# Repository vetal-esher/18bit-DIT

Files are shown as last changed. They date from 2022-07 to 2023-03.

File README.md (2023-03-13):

# 18bit-DIT
Adding  digital output for old synths

Surely everyone who used to know DOS era met in games the choice of musical accompaniment - General MIDI, Roland Sound Canvas, Yamaha XG. I will not talk about what wonderful devices these are, and how well they played MIDI. Until the end of the 90s, all these home desktop romplers, like most other professional devices, had only analog outputs, however, they were quite acceptable in quality. In early 2010, out of nostalgia, I bought several devices of that era on ebay - these are the Roland Sound Canvas 88 Pro, <a href="https://github.com/vetal-esher/MT32-DIT">Roland MT-32</a>, Yamaha MU128 and Yamaha AN200. The first three should be familiar to gamers of the early 90s, while the AN200 module is an analog modeling synthesizer based on the Yamaha PLG150-AN plug-in card. Later Yamaha MU1000/2000 tone generators were also sold on the site - their difference from the MU128 consisted in a slightly expanded version of the sample bank, as well as in the presence of an optical TOSLINK output.

Actually, the presence of optics in the MU2000 prompted me to start comparing circuits to see if it was possible to modify the MU128 circuit and get a digital output on my own. In the MU2000 service manual, the optical output circuitry is based on a proprietary Yamaha YM3437C chip, which is very difficult to get for an ordinary radio amateur. We need to look for a more general DIT. A Google search on this topic led me to a <a href="https://nfggames.com/forum2/index.php?topic=4063.0">mod for MU10</a>. The author of the mod relied on the <a href="http://www3.big.or.jp/~fujikko/sc88vl/kaizo.html">Japanese mod for the Roland SC-88VL</a>. The mod is based on the TC9231N chip from Toshiba, which implements a digital audio interface according to the SPDIF/TOSLINK standard. The chip can be ordered on ebay, it costs an average of $ 2.5 per piece (note: this was in 2010, now the chip is almost impossible to find); the rest of the parts are sold at any radio store. I assembled a Japanese version on a breadboard, and it turned out to be working - with a small caveat. The DAC of the Roland SC88 is 18-bit, while the TC9231N is 16-bit. The Japanese author made a binding for this, which allows either cutting off the top 2 bits in the stream - which could lead to clipping, or shifting the stream 2 bits lower (cutting off the bottom 2 bits), which led to a decrease in volume. In any case, 2 bits of information were lost - and that did not suit me.
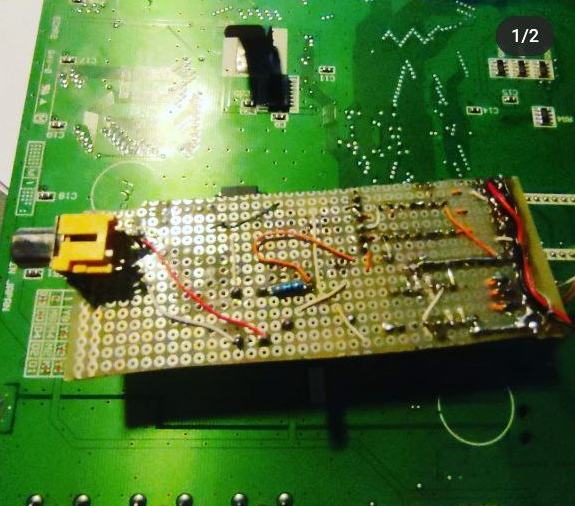
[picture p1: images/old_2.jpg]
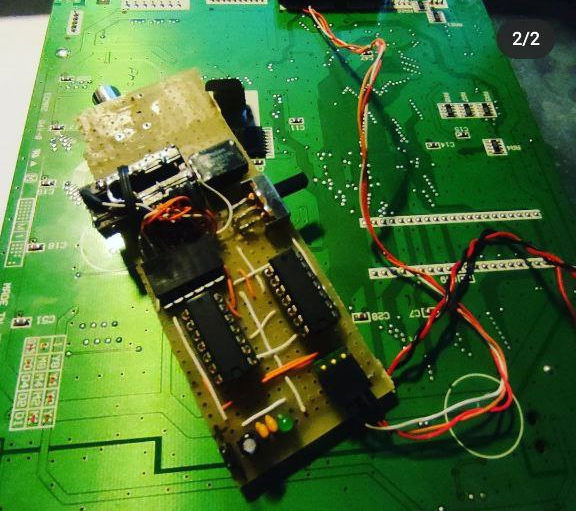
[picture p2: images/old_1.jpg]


I started looking for a transceiver that works with 18-bit stream in "hardware" mode, i.e. that does not require setting the operating mode using an additional microcontroller. After a lot of experimentation with DIT 4096, 4192, TC9271N and others, I finally found a transceiver that works native with 18-bit stream - AKM AK4103AVF. Thanks to the internal pull-up and pull-down resistors, you can build the scheme by minimum of components.

Let's sketch out the diagram first. Given that the board should be as versatile as possible, all configurable pins should be placed on jumpers. The output is bound according to the datasheet as consumer S/PDIF. If XLR AES3 (AES/EBU) is needed, see AK4103 datasheet, also there you need another configuration on FS0-FS3 pins.

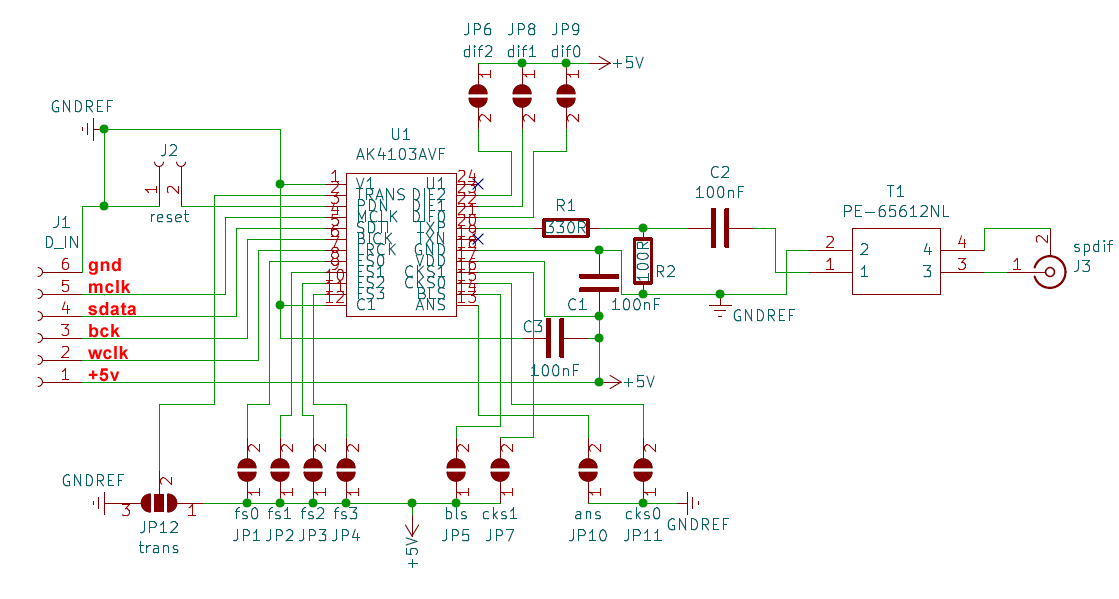
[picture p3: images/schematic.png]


The input is I2S, for this we need the sdata, lrck(wclk), bck and mclk lines on the sources. In different datasheets, these lines may be called differently, but their essence is always the same - DATA=SDATA=SI=MDAC=SDTI, LRCK=LRCX=MWCLK, CLK=MQCLK=BCK, etc. All of these lines should be easily found in the circuits included in the DAC, with the exception of mclk, which will have to be searched by the oscilloscope at different points in the circuit. Usually, in I2S, mclk is not needed for transmission, but in AK4103AVF the line is used for correct synchronization.

It has been noticed that if the circuit is turned on at the same time as the module, the AK4103 does not pick up the frequency and the digital output is silent. Empirically revealed that the frequency is caught after the initialization of the module, you need a power delay. In 2016, without thinking twice, I simply brought the "spdif reset" button to the case (shown in the diagram). At the beginning of June 2022, <a href="https://github.com/nikitalita/MU100-DIT">nikitalita</a> contacted me and suggested to use the BRESET line in the PLG expansion connector. An oscilloscope check revealed that BRESET remained low for about 70ms, which was enough for the DIT to pick up the frequency. Let's find the lines on all three devices:

<table border=1>
<tr><th>I2S</th><th>Roland SC-88 Pro</th><th>Yamaha MU128</th><th>Yamaha AN200</th></tr>
<tr><td>mclk</td>	<td>CN105 pin 5</td>	<td>IC39 pin 16</td>	<td>IC17 pin 160</td></tr>
<tr><td>sdata</td>	<td>CN105 pin 3</td>	<td>IC36 pin 15</td>	<td>IC16 pin 15</td></tr>
<tr><td>bck</td>	<td>IC35 pin 8</td>	<td>IC36 pin 16</td>	<td>IC16 pin 16</td></tr>
<tr><td>wclk</td>	<td>CN105 pin 6</td>	<td>IC36 pin 13</td>	<td>IC16 pin 13</td></tr>
<tr><td>reset</td>	<td>IC35 pin 9</td>		<td>IC34 pin 19</td>	<td>CN5 pin 4</td></tr>
</table>

<h3>Roland SC-88 Pro</h3>
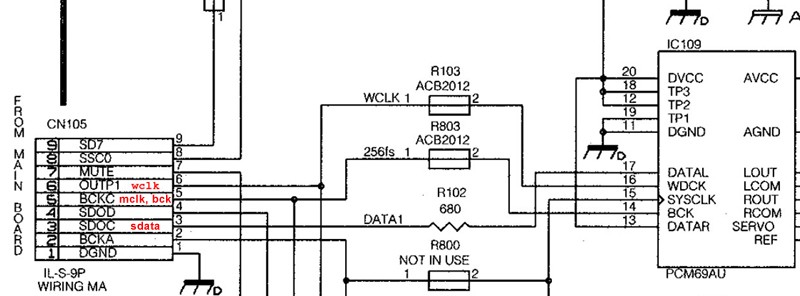
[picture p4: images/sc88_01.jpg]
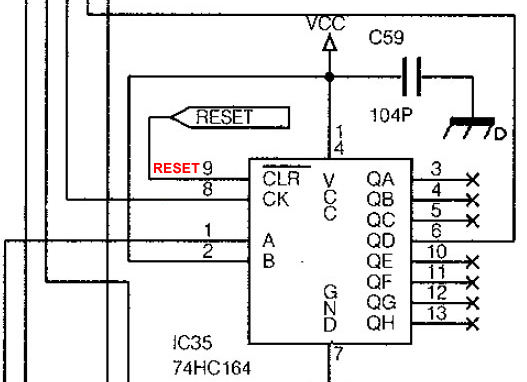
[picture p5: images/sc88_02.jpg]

<h3>Yamaha MU128</h3>
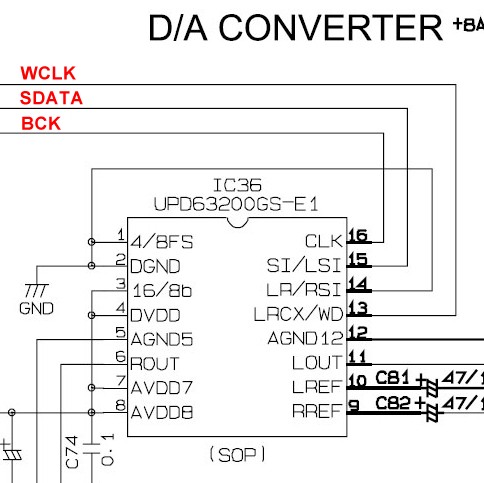
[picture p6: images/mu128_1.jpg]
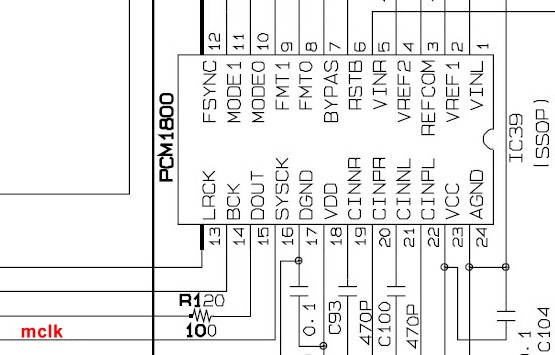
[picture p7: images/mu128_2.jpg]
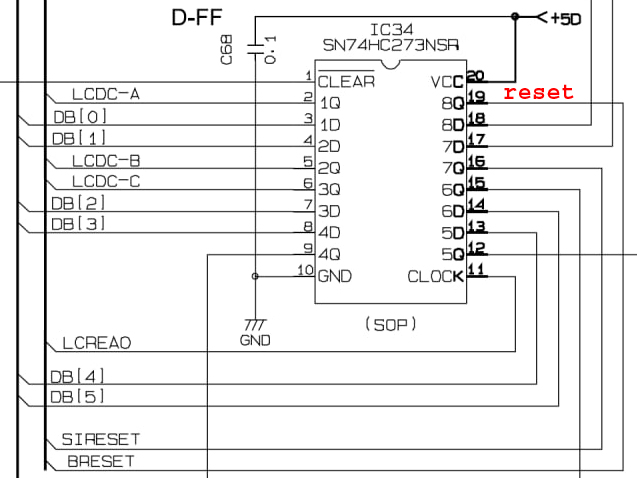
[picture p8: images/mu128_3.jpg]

<h3>Yamaha AN200</h3>
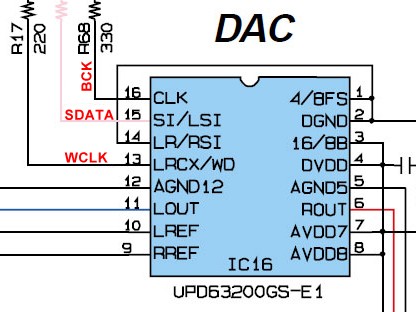
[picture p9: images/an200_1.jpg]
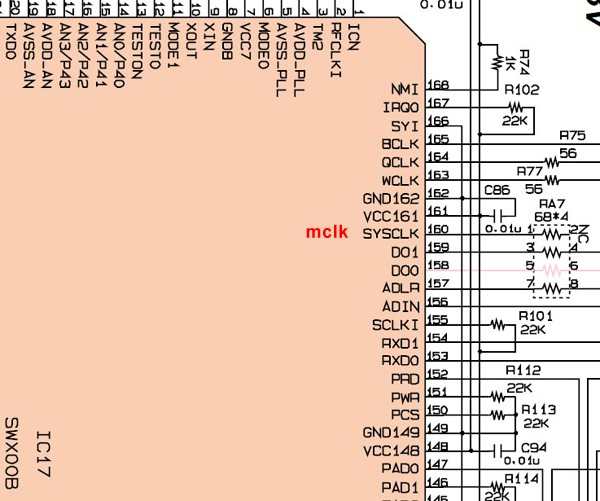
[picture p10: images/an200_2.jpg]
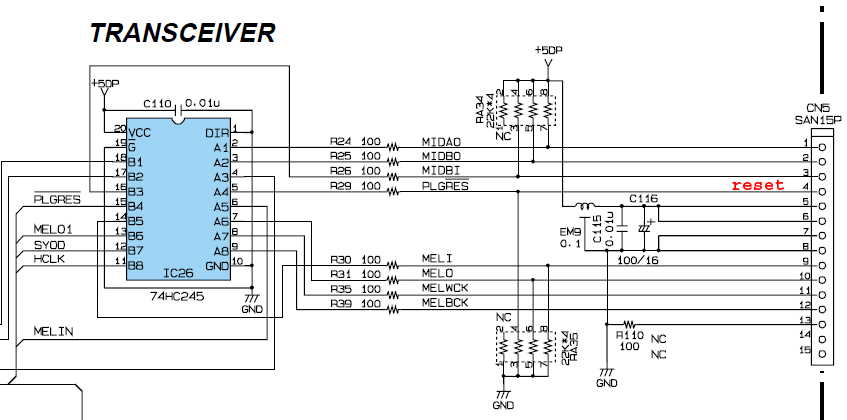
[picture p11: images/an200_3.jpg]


The SC88 has an 18-bit PCM69AU, while the MU128 and AN200 have an 18-bit NEC D63200. According to the specification, the SC-88 has a sample rate of 32kHz, MU128 and AN200 - 44kHz. Following the datasheet, we need to set the following modes: audio routing mode - normal, synchronous mode, 18bit right justified. Let's measure frequencies:
<table border=1>
<tr><th></th><th>wclk</th><th>mclk</th><th>bck</th><th>dif0</th><th>dif1</th><th>dif2</th><th>cks0</th><th>cks1</th><th>fs0</th><th>fs1</th><th>fs2</th><th>fs3</th></tr>

<tr><td>default</td><td>-</td><td>-</td><td>-</td><td>0</td><td>0</td><td>0</td><td>1</td><td>0</td><td>0</td><td>0</td><td>0</td><td>0</td></tr>
<tr><td>SC88</td>
<td>32000Hz</td><td>8.192 MHz</td><td>8.192 MHz</td>
<td>1</td><td>0</td><td>0</td>
<td>1</td><td>0</td>
<td>1</td><td>1</td><td>0</td><td>0</td>
</tr>
<tr><td>MU128</td>
<td>44100Hz</td><td>11.2896 MHz</td><td>2.8224 MHz</td>
<td>1</td><td>0</td><td>0</td>
<td>1</td><td>0</td>
<td>0</td><td>0</td><td>0</td><td>0</td>
</tr>
<tr><td>AN200</td>
<td>44100Hz</td><td>16.9344 MHz</td><td>2.8224 MHz</td>
<td>1</td><td>0</td><td>0</td>
<td>0</td><td>1</td>
<td>0</td><td>0</td><td>0</td><td>0</td>
</tr>
</table>

By the way, in 2010, the service manual for the MU128 could only be found on the same Ebay for money. I bought it, got a PDF, and immediately shared it on my site for free for everyone who seeks it. After a few weeks, this service manual was no longer sold :)

<p>This circuit was assembled on a breadboard and successfully worked in MU128 and AN200 in 2016.</p>

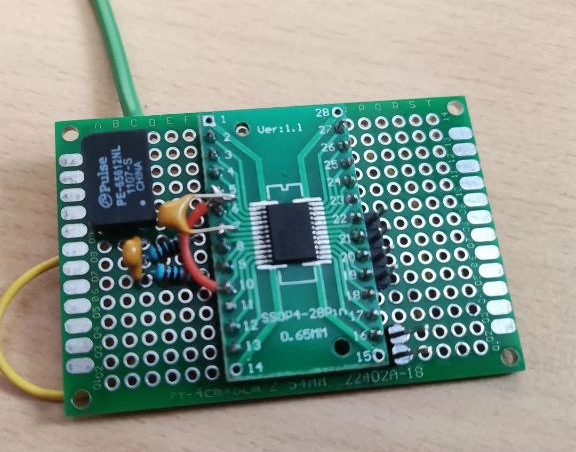
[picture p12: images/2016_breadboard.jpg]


In 2021, I suddenly decided to re-release the development in a decent way.

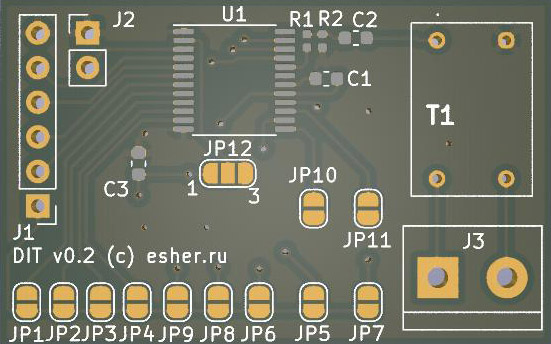
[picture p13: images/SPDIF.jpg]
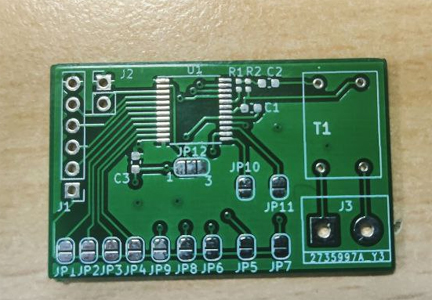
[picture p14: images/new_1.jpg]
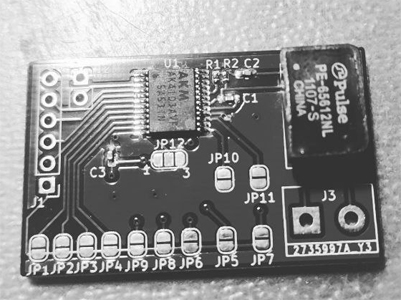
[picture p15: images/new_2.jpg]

<p>Gerbers: <a href="hardware/gerber/dit_0.2_gerber.zip">dit_0.2_gerber.zip</a></p>
<h2>Partlist</h2>
<table border=1>
<tr><th>Reference</th><th>Value</th><th>Package</th></tr>
<tr><td>U1</td><td>AK4103AVF</td><td>TSSOP-24</td></tr>
<tr><td>T1</td><td>PE-65612NL, TC-612</td><td></td></tr>
<tr><td>C1, C2, C3</td><td>100nF</td><td>0603</td></tr>
<tr><td>R1</td><td>330R</td><td>0402</td></tr>
<tr><td>R2</td><td>100R</td><td>0402</td></tr>
</table>

<h2>Roland SC88 Pro notes</h2>
<p>According to Japanese DIT project, the actual stream is 20bit, so AK4103 can be configured as 20-bit right justified, but you will get only significantly lower volume. This is the same melody recorded 20-bit first, then 18-bit:</p>

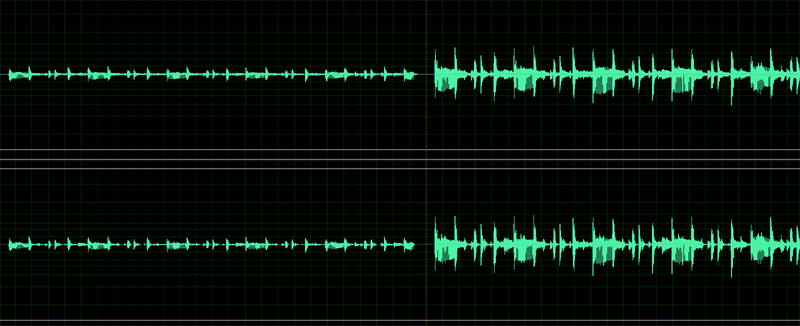
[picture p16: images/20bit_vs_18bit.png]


<h2>Links</h2>
<p><a href="https://esher.ru/blog/887.html">https://esher.ru/blog/887.html</a> My initial blog post in 2016 </p>
<p><a href="https://github.com/nikitalita/MU100-DIT">MU100-DIT</a>, a parallel project for MU-series using TOSLINK, by nikitalita</p>
<p><a href="https://kurohane.net/wiki/index.php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">Japanese project using AK4103 too</a></p>
<p><a href="https://esher.ru/i/f/887/887/AK4103AVF.pdf">AKM AK4103A datasheet</a></p>
<p><a href="https://esher.ru/i/f/900/900/an200sm.pdf.gz">Yamaha AN200 service manual</a></p>
<p><a href="https://esher.ru/i/f/888/888/Roland_SC-88Pro_ServiceNotes.pdf.gz">Roland SC88 Pro service notes (in japan)</a></p>
<p><a href="https://esher.ru/i/f/869/869/mu128sm-e.pdf.gz">Yamaha MU128 service manual</a></p>
<p><a href="https://github.com/vetal-esher/MT32-DIT">MT32-DIT, trying to SPDIF the legendary Roland MT-32</a></p>

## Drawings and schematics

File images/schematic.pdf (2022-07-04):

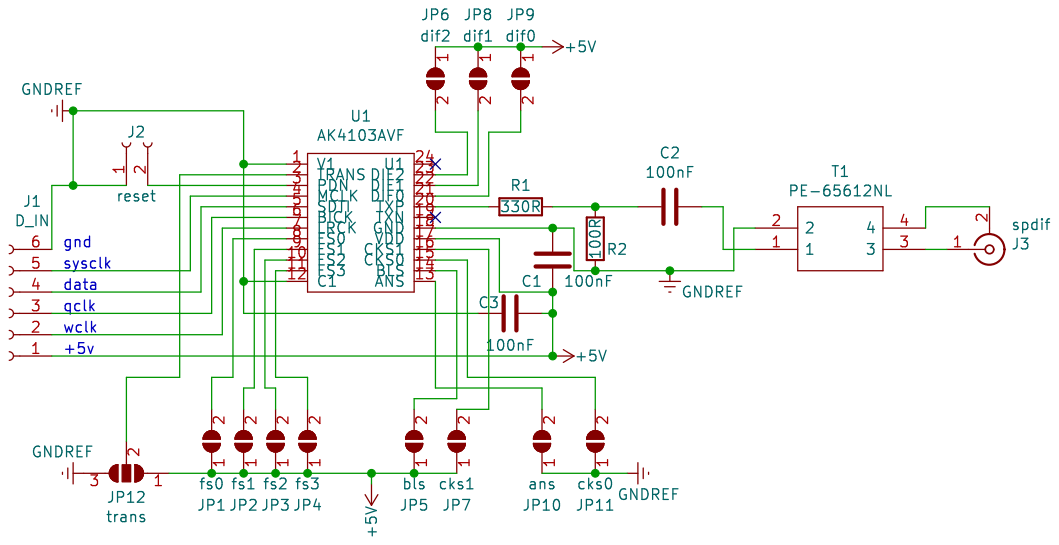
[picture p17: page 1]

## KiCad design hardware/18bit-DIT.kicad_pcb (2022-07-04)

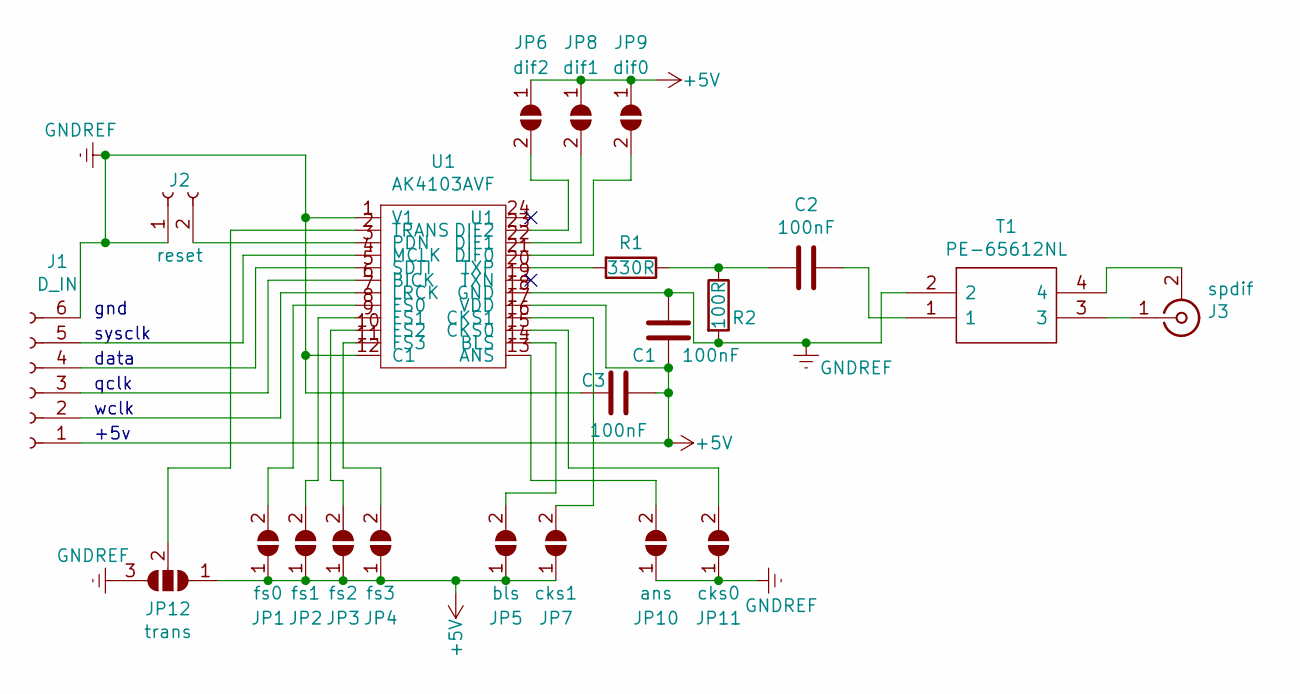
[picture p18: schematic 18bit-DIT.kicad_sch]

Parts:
C1, C2, C3: 100nF; C_0603_1608Metric
J1: D_IN; PinHeader_1x06_P2.54mm_Vertical
J2: reset; PinHeader_1x02_P2.54mm_Vertical
J3: spdif; TerminalBlock_bornier-2_P5.08mm
JP1: fs0; SolderJumper-2_P1.3mm_Open_RoundedPad1.0x1.5mm
JP2: fs1; SolderJumper-2_P1.3mm_Open_RoundedPad1.0x1.5mm
JP3: fs2; SolderJumper-2_P1.3mm_Open_RoundedPad1.0x1.5mm
JP4: fs3; SolderJumper-2_P1.3mm_Open_RoundedPad1.0x1.5mm
JP5: bls; SolderJumper-2_P1.3mm_Open_RoundedPad1.0x1.5mm
JP6: dif2; SolderJumper-2_P1.3mm_Open_RoundedPad1.0x1.5mm
JP7: cks1; SolderJumper-2_P1.3mm_Open_RoundedPad1.0x1.5mm
JP8: dif1; SolderJumper-2_P1.3mm_Open_RoundedPad1.0x1.5mm
JP9: dif0; SolderJumper-2_P1.3mm_Open_RoundedPad1.0x1.5mm
JP10: ans; SolderJumper-2_P1.3mm_Open_RoundedPad1.0x1.5mm
JP11: cks0; SolderJumper-2_P1.3mm_Open_RoundedPad1.0x1.5mm
JP12: trans; SolderJumper-3_P1.3mm_Open_RoundedPad1.0x1.5mm_NumberLabels
R1: 330R; R_0402_1005Metric
R2: 100R; R_0402_1005Metric
T1: PE-65612NL; PE65612NL; Manufacturer_Part_Number PE-65612NL; Mouser Part Number 673-PE-65612NL
U1: AK4103AVF; TSSOP-24_6.1x7.8mm_P0.65mm

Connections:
+5V: C1.2, C3.1, J1.1, JP1.1 (A), JP2.1 (A), JP3.1 (A), JP4.1 (A), JP5.1 (A), JP6.1 (A), JP7.1 (A), JP8.1 (A), JP9.1 (A), JP12.1 (A), U1.17 (VDD)
GNDREF: C1.1, C3.2, J1.6, J2.1, JP10.1 (A), JP11.1 (A), JP12.3 (B), R2.2, T1.2, U1.1 (V1), U1.12 (C1), U1.18 (GND)
unnamed: C2.1, T1.1
unnamed: C2.2, R1.1, R2.1
unnamed: J1.2, U1.7 (LRCK)
unnamed: J1.3, U1.6 (BICK)
unnamed: J1.4, U1.5 (SDTI)
unnamed: J1.5, U1.4 (MCLK)
unnamed: J2.2, U1.3 (PDN)
unnamed: J3.1 (In), T1.3
unnamed: J3.2 (Ext), T1.4
unnamed: JP1.2 (B), U1.8 (FS0)
unnamed: JP2.2 (B), U1.9 (FS1)
unnamed: JP3.2 (B), U1.10 (FS2)
unnamed: JP4.2 (B), U1.11 (FS3)
unnamed: JP5.2 (B), U1.14 (BLS)
unnamed: JP7.2 (B), U1.16 (CKS1)
unnamed: JP10.2 (B), U1.13 (ANS)
unnamed: JP11.2 (B), U1.15 (CKS0)
unnamed: JP12.2 (C), U1.2 (TRANS)
unnamed: R1.2, U1.20 (TXP)
unnamed: JP9.2 (B), U1.21 (DIF0)
unnamed: JP8.2 (B), U1.22 (DIF1)
unnamed: JP6.2 (B), U1.23 (DIF2)

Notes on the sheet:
+5v
sysclk
qclk
gnd
data
wclk

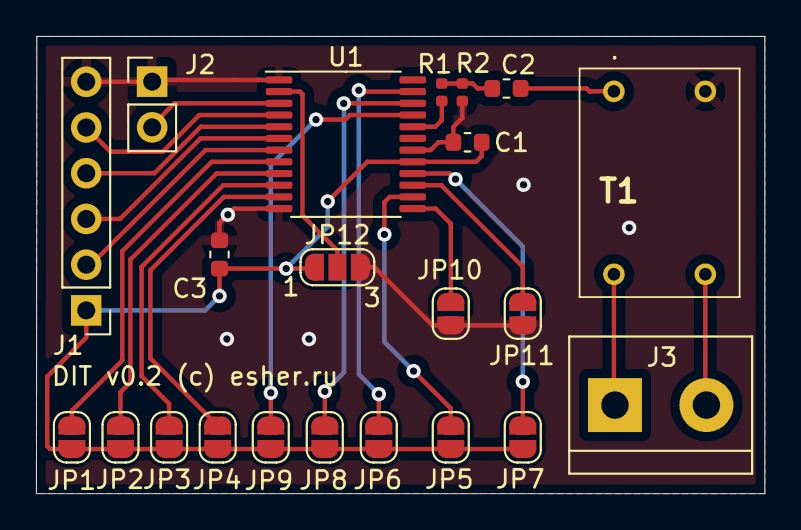
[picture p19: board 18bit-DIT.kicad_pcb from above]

Board: 2 copper layers, 40.5 x 25.4 mm, 22 parts (0 on the bottom side), 24 nets.

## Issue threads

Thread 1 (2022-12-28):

Enhancement: IC options

lje, 2022-12-28:
The AK4103AVF seems to be discontinued and out of stock. Will you update the project to other IC options like WM8804G?

vetal-esher, 2022-12-28:
May be, although i don't have any WM8804  and working now on another project about DIT-ting MT32. So, AK4103 is out of stock? That's pity, is was fine chip with 18bit support.

lje, 2022-12-28:
Digikey states obsolete/out-of-stock. I had no luck finding one on Aliexpress or eBay as well. Same for TC9271N.
The 16bit TC9231N can still be bought easily, as well as the WM8804G.
This is the situation for Germany/Europe at least, it may be different on other continents.

Out of curiosity, I'm looking forward to your MT32 project. I only got an SC88VL myself and know the japanese 16bit option you linked as well, but are looking to get/make an 18bit mod for it.

vetal-esher, 2022-12-28:
MT32-DIT is based on Gowin FPGA (as the cheapest solution) and DIT4192, the only thing stopping me from publishing it is that the project is not ready yet. PS. due to war sanctions, Digikey, Mouser and others have banned russian IPs, so i don't know the availability of DIT4192 too. WM8804 can be found at Aliexpress, so i need to order some of them

lje, 2022-12-28:
Mouser doesn't even know the AK4103 (searched for AK4103, AK4103A and AK4103AVL). DIT4192 is available on both Digikey and Mouser.

vetal-esher, 2023-01-27:
Btw, AK4103 is now available at Aliexpress, at least one seller has it.

vetal-esher, 2023-02-11:
> Digikey states obsolete/out-of-stock. I had no luck finding one on Aliexpress or eBay as well. Same for TC9271N. The 16bit TC9231N can still be bought easily, as well as the WM8804G. This is the situation for Germany/Europe at least, it may be different on other continents.
>
> Out of curiosity, I'm looking forward to your MT32 project. I only got an SC88VL myself and know the japanese 16bit option you linked as well, but are looking to get/make an 18bit mod for it.

I have published MT32-DIT project, it is not done yet, but the hardware part is finished. Project will be updated when the progress goes forward.

lje, 2023-02-14:
I found a seller for the AK4103 on Aliexpress now, thanks. Thanks to your Gerber files, I've ordered PCBs at JLCPCB now. Since they currently offer assembly basically for free, I'll have them solder the capacitors and resistores as well (I've added a suitable BOM and CPL to this comment). I'll have to manually solder the AK4103 and the PE-65612NL.

I noticed that they have a [WM8804G in their parts library](https://jlcpcb.com/partdetail/CirrusLogic-WM8804GEDSRV/C323843). In case you create modified version of this project using a WM8804G, people could order PCBs with all the SMD parts pre-soldered, leaving only the PE-65612NL for manual soldering.

[JLCPCB-BOM.csv](https://github.com/vetal-esher/18bit-DIT/files/10734641/JLCPCB-BOM.csv)
[JLCPCB-CPL.csv](https://github.com/vetal-esher/18bit-DIT/files/10734642/JLCPCB-CPL.csv)

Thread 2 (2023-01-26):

Sound Canvas SC-55

Veda82, 2023-01-26:
Hi, I was wondering if this could be used also with a Sound Canvas SC-55.

In particularly, which input points shall be used for sysclk, data, qclk, wclk and reset?

Thanks in advance!

vetal-esher, 2023-01-27:
According to SC55 service manual, you should look at DAC IC7 - UPD6376, where13pin@IC7 - LRCK(WCLK), 15pin@IC7 - SDATA, 16pin@IC7 - BLCK.

SC-55 is described as 16bit 32kHz, for that bit clock should be (16*2*32000)=1.024MHz, and the master clock must be bclk*2 or bclk*4 or *8 or *16. Reset line can be found at IC21 pin 21 or IC31 pin 1.

Master clock needs to be found at the clk pins mentioned in service manual, without real device i can't say for sure which line is valid for that.

Veda82, 2023-01-27:
Ok, I will try using your informations.

Thanks for your work/project and support!

vetal-esher, 2023-01-27:
Don't forget that you must configure dif0-dif2 , fs0-fs3 according to 16bit right justified , 32kHz, and cks0-cks1 according to mclk/lrckr divide.

Veda82, 2023-01-27:
Yes, already noticed, thank you!

Still waiting for the boards/components...

Once I try I'll report my findings.

vetal-esher, 2023-03-07:
Just for attention, in neighbor issue we found that the MCLK pin  also can be feed with BCK line. It works.

Veda82, 2023-03-07:
Thanks! Unfortunately I'm still waiting for the chips... eBay supplier was a scam, let's hope I have more luck from AliExpress...

vetal-esher, 2023-03-07:
I ordered from Ali 3 weeks ago, and the chips are already in country going to my city.

vetal-esher, 2023-06-09:
> Thanks! Unfortunately I'm still waiting for the chips... eBay supplier was a scam, let's hope I have more luck from AliExpress...

So, any news, have you tried the mod?

Veda82, 2023-06-09:
Got the parts, will try in a few days...

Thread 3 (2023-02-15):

Sound Canvas 88-VL

lje, 2023-02-15:
I'm trying to adapt the design to SC88VL (a small version of the SC88 with the size of a SC55). The service manual [is available](https://www.google.com/search?q=roland+sc88vl+service+manual).

Getting DATA, WCLK and SYSCLK(?) is convenient, as there are unused solderpoints on the mainboard as outlined by the[ japanese project](http://www3.big.or.jp/~fujikko/sc88vl/kaizo.html) you already link to (C32-C34).

Getting QCLK(?) and RESET will be more effort, those are not needed for TC9231N but are needed for AK4103 (the lower part is IC36)
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

I'm not completely sure if I may be mixing up QCLK and SYSCLK. On your main page you write "CLK=MQCLK". But on your annotations for SC88 pro, CK = QCLK. In SC88VL, there is a CK pin as well on IC36, meaning the BCLK, which Roland also names CLK, is probaby SYSCLK. Can you help me verifying signals?

Access to CK may be possible at R80/C98 right next to IC36.
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

For RESET multiple options are available - maybe IC1 directly at the heat sink.

vetal-esher, 2023-02-15:
These names like CLK, SYSCLK, SCLK etc. are very confusing, i agree. Let's try to think in I2S signals names.
For I2S, we need
DATA (SI - serial input) - pin15@IC14
WCLK(word clock, or LRCK - left right clock) - pin13@IC14. Must be 32000 Hz.
BCLK (bit clock) - pin16@IC14.

MCLK (master clock) needs to be found at pins which have 'CK' part, e.g. clock.
Pin 58@VL's IC36 is definitely 24.576MHz, for 32kHz you need 768fs mode, but AK4103 max fs is 512, so you need to find on board divided clock, at least 16.384MHz or 8.192MHz.

By luck, on SC88 Pro IC35 (74HC164) there was CK pin 8 with 8.192MHz.

vetal-esher, 2023-02-15:
If the DIT will work, please share where you've found all these lines, i'll create additional chapter with updates for different synth models.

lje, 2023-02-16:
Hopefully that question is not totally stupid: could I just use BCLK from the SC88VL and connect it to both BCLK and MCLK, or do BCLK and MCLK deviate from each other? Both are 8.192MHz in your SC88Pro example.

I checked the board for a suitable crystal, but only found 20MHz so far. And the AK4103 manual states that MCLK and LRCK should be derived from the same clock signal anyway, so any other (unrelated) crystal having a suitable frequency probably won't work.

So if BCLK cannot be used as MCLK, the solution may be a frequency devider (1/2, as 384fs is supported) or a DIT that doesn't need MCLK like the TC9271N/F. They support 18bit LSB w/o MCLK but seem to be unobtainium.

vetal-esher, 2023-02-16:
Hmm, i just checked both BLCK and MCLK  on SC88Pro and the seem to be identical. I don't know why but as far as i remember the board was not working when i feed only BCK line to both BCK and MCLK inputs on AK4103. You should try, from my side i will test it tonight and return with results.

vetal-esher, 2023-02-16:
I confirm that feeding BCK@SC88Pro to both BCK@DIT and MCLK@DIT is working. I don't know why it have not worked in the past, afair i tested it couple of times.

vetal-esher, 2023-02-16:
The reason that it is working in Right Justified mode, i think. AK4103 takes only first 18 bit and the left within L/RCLK frame is just skipped.

lje, 2023-02-16:
Great, thanks - that means I can use your board with SC88VL. Now I just need to wait for everything to arrive. Meanwhile I'll look for suitable spots to get GND, 5V and RESET. And I still need to order a cinch-connector for J3. RESET goes to the circular pad of J2, correct?

vetal-esher, 2023-02-16:
Yes, circular of J2 is RESET line. You don't need connector, just solder the wire. GND and 5V are easily taken at any capacitor in 5v/gnd streams, or at corresponding IC pins. Note that at J1 the square (first) pin is 5V, as in schematic.

vetal-esher, 2023-02-16:
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

I used floating method, hiding dit in heatshrink, and covering wires with el.tape

lje, 2023-03-07:
Board from JLCPCB came, caps and resistors presoldered nicely. I'm still waiting for the DIT-ICs. I just wanted to verify jumper settings with you (for SC88):

```
+5V Jumpers
JP1  fs0   -> 1 - +5V
JP2  fs1   -> 1 - +5V
JP3  fs2   -> 0 - NC
JP4  fs3   -> 0 - NC
JP5  bls   -> ??? (NC in your photograph)
JP7  cks1  -> 0 - NC

JP6  dif2  -> 0 - NC
JP8  dif1  -> 0 - NC
JP9  dif0  -> 1 - +5V

GND Jumpers
JP10 ans   -> 1 - NC
JP11 cks0  -> 1 - NC

GND/+5V
JP12 trans -> 0 - GND
```

In your photograps it looks as if there are solder blobs on JP8, but I guess they're not connected.
"bls" is missing in your settings table for SC88/MU128/AN200 and not mentioned anywhere in the text. In your photograph it is not connected.

I've attached a picture with all jumpers I need to connect for SC88 - correct?
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

vetal-esher, 2023-03-07:
Let's recheck the datasheet defaults and tables. We need 32kHz, audio routing mode - normal, synchronous mode, 18bit right justified.

Default values
JP1  fs0  (Pull-down Pin)
JP2  fs1 (Pull-down Pin)
JP3  fs2 (Pull-down Pin)
JP4  fs3 (Pull-down Pin)
JP5  bls (Pull-down Pin)
JP7  cks1 (Pull-down Pin)

JP6  dif2 (Pull-down Pin)
JP8  dif1 (Pull-down Pin)
JP9  dif0 (Pull-down Pin)

JP10 ans (Pull-up Pin)
JP11 cks0 (Pull-up Pin)

JP12 trans - no default, 0: Normal mode, 1: Audio routing mode (transparent mode)
---------------
So we need to short JPs which must be not in default mode.
According to tables in datasheet, modes that we need:

18bit, Right justified =  DIF2 DIF1 DIF0 = 0 0 1
Synchronous mode + Audio routing Normal mode = ANS	TRANS = H(1) L(0)
32kHz = FS3 FS2 FS1 FS0 = 0 0 1 1
MCLK FS 256 = CKS1 CKS0 = 0 1

So, we need:
Short the DIF0 (JP9)
Short the TRANS to GND (2-3)
Short the FS0 (JP1) and FS1 (JP2)

JP8 is open, i shorted is when tested the board with 20bit resolution as mentioned in article.

lje, 2023-06-11:
I got demotivated by my poor SMD soldering skills and paused the project for some time. Since I had 5 PCBs, I ordered 3 chips to have multiple tries soldering them. Board 1 looks best to me, with board 2 the right side of the chip is a bit misligned but it still seems to be ok, with board 3 I damaged some traces and there is still one short on the right side that needs to be fixed by desoldering braid. I'm glad I ordered the boards with resistors and capacitors pre-soldered, I would have given up otherwise. That stuff is too tiny for my skills.
I'll probably continue with the first board. Next step will be soldering a pin header to C32, C33, C34 and a suitable 5V spot.

Board 1
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

Board 2
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

Board 3
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

vetal-esher, 2023-06-11:
You should use tweezers and the hot air gun for soldering smd components. There are number of videos on youtube with smd soldering. Number 1 board is not that bad, take some copper braid for desoldering, use flux. If it can help, i can record video how i solder this board, i have 3 of them ready for assembly.

lje, 2023-06-11:
Yeah I found one, example https://www.youtube.com/watch?v=rgcupYOnvBo
I soldered the ICs with a soldering iron (TS 100) which is probably not the best way to do it. I'll have more time the weekend after the next and will try to fix the shorts on board 1

lje, 2023-06-26:
What's the power consumprtion of the board? The SC88VL offers "+5V" which is provided by an 77L50 (100mA max) as well as VCC provides by an 88R05 (1A). I guess it would be wise to attach to VCC/88R05.
